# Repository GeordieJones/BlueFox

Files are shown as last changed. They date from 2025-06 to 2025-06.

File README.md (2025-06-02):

# BlueFox

blueFoxLogo_1

**DISCRIPTION:** BlueFox is a modular mesh network system that uses ESP-32 CAM's that take images of a location every 30 minutes then transmit them back to my home computer via LoRa protocol. The network comprises of end nodes (the ESP CAMs); relay nodes (the LoRa-32 cases outside of my house); and the central node (the LoRa-32 at my house). Due to the limited bandwidth of LoRa and the relitave size of the images I decided to change the image to FRAMESIZE_QQVGA in order to make the data needing to be sent to be smaller the code can send larger images it just takes a longer time due to the greater number of packets needing to be sent. Even with the smaller images LoRa cannot send the image with one radio.transmit() so I created hex packets with a header for identification, ending for termination, and checksums to insure all data was received correctly. With this each relay node will collect all the packets for the last one and then move it forward untill it reaches the end. One at the central node it will hex dump all of the data removing headers, endings, and checksums to be copied in to a python script that will remake the image from the hex. Each node is held in a 3D printed PETG case which is weatherproof and has a 5 dBi antenna for increased range.

**Process:** orgininaly the plan was to have the CAM unit be connected to a STM32 microboard which then connected to a LoRa-32 for sending. However this was scrapped due to the large size and wiring which could become seperated in extreme enough weather conditions. It was then decided to use the ESP-32's onboard WiFi chip which allows one board to be the host for another. This choice proved to be optimal due to the lack of physical constraints and WiFi's high bandwidth which allowed for a smaller case with better resistance to disturbances to the case.  

**STM + CAM + LoRa idea:**



**Just CAM + LoRa idea:**



**Testing:** in order to make sure the boxes could hold up to the weather and not short circut in extreme weather conditions I created test boxes. These boxes held a voltage stepper, which was only used becasue it was a small, expendible,and had a LED which could be used to determine if the board survived and could still function. The box also contained a small bit of tissue to indicate whether or not water got into the box or not. I created two boxes PLA (the control group named reaper) and PETG (higher streght material named terminator). These boxes where then ratchet strapped to stands and left outside for a week. The weather during this week included 3 thunderstorms, a flood watch, and two 85 degree sunney days giving the boxes a good test set. Additionaly the boxes where put in a sauna for 30 minutes at 170 degrees.








**RESULTS:** after the week was done the boxes where removed and opened to test the hardware. The tissue was damp on the PLA box and had a few drop marks on the PETG box. Both boxes voltage steppers LED's worked indicating the boxes did there intended job. In the sauna the PLA box did not melt but became extremely soft to the point where you could push a hole in it with almost no effort while the PETG box held firm as expected due to it's higher melting point.

**FINAL MAKE:** with the test complete and the code working I created the final designs to hold the boards, batteries, antennas, and camera. The range of each mesh is around 0.6 miles in a suburban highley wooded area but is dramatically increased if the the senders hight is increased.

Screenshot 2025-05-31 at 7 55 28 PM



**EXTRA NOTES:** When printing with the screws I highly recommend giving youself tolerances as it is very easy to make a screw too big for the hole, I usually use a .2 - .3 mm offset. Additionally, when programming the LoRa it is very important to make sure you are using the Library that matches the chip on your board originaly when I was trying to use the LoRa.h library I was missing packets and getting false data I had to change to the LoRaWan_APP.h library to get my messages to work coherently.

**MATERIALS USED:**  

 **- ESP32-CAM Ai Thinker Model** – [link](https://www.amazon.com/ESP32-CAM-MB-Aideepen-ESP32-CAM-Bluetooth-Arduino/dp/B0948ZFTQZ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)  
 **- Heltec LoRa V3 WiFi** – [link](https://www.amazon.com/dp/B076MSLFC9?ref=ppx_yo2ov_dt_b_fed_asin_title&th=1)  
 **- LiPo Battery** – [link](https://example.com/link-to-cam)  
 **- Antenna** – [link](https://www.amazon.com/dp/B0DLK6BG3L?ref=ppx_yo2ov_dt_b_fed_asin_title)  
 **- PLA Basic** – [link](https://us.store.bambulab.com/products/pla-basic-filament)  
 **- PETG HF** – [link](https://us.store.bambulab.com/products/petg-hf)  

**INSPIRATION:** the cases are each named after a top gun character as maverick is the main character it is the CAM, goose is the wing man and relaying the data, and iceman is the commander and most reliable.
The name blueFox comes from a cold war project that built covert long range image and data transmittion. Hense why this project is named blueFox because it's intention is to be a covert camera sytem that can send images over long ranges.

ChatGPT_Image_Jun_1_2025_at_01_08_06_PM

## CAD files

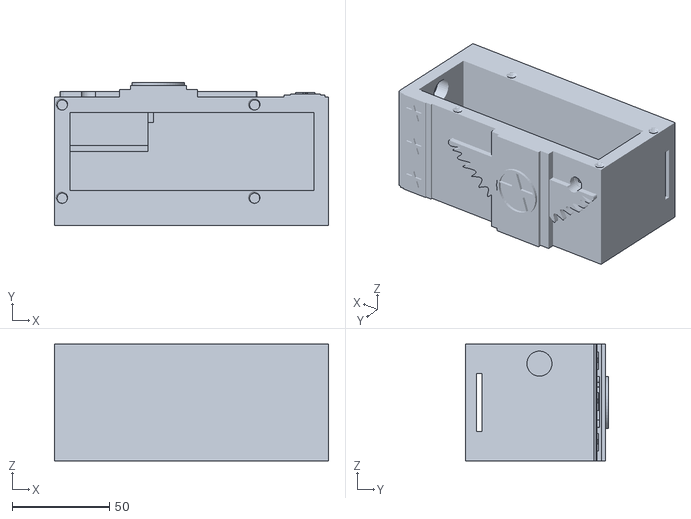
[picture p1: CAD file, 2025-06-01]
STL_files/MAVERICK case.stl
141.0 x 73.5 x 60.0

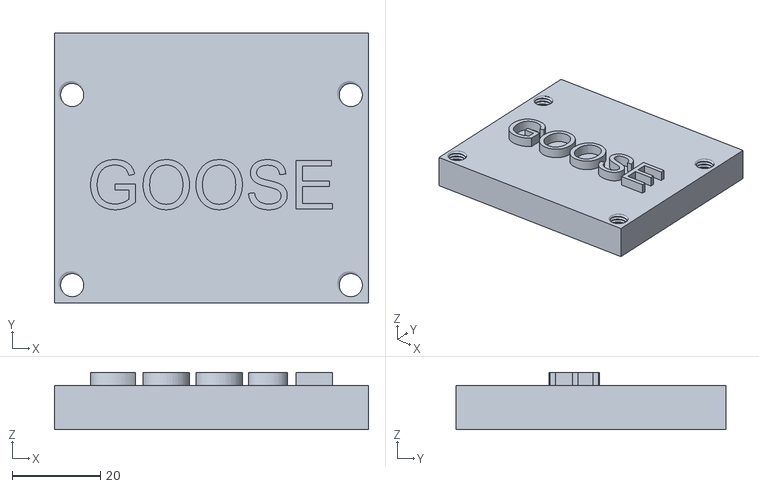
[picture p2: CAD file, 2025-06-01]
STL_files/Goose Top.stl
71.0 x 61.0 x 13.0

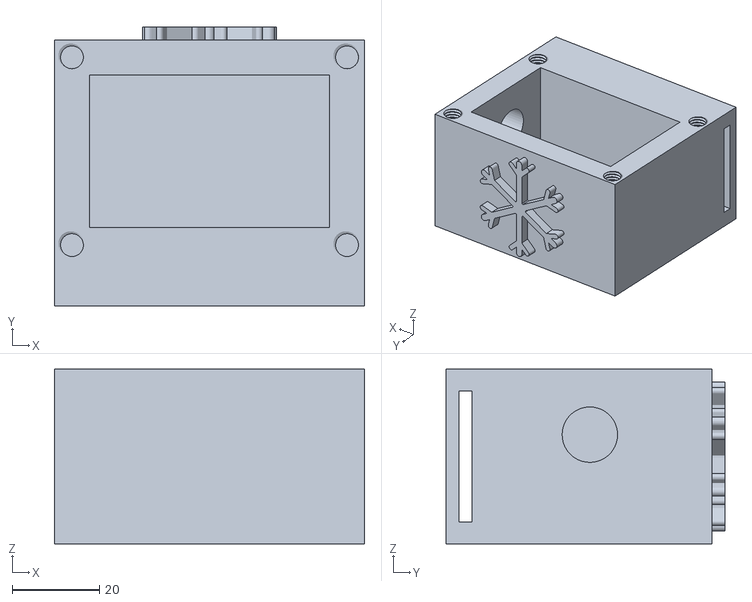
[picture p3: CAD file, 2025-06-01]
STL_files/ICEMAN CASE.stl
71.0 x 64.0 x 40.0

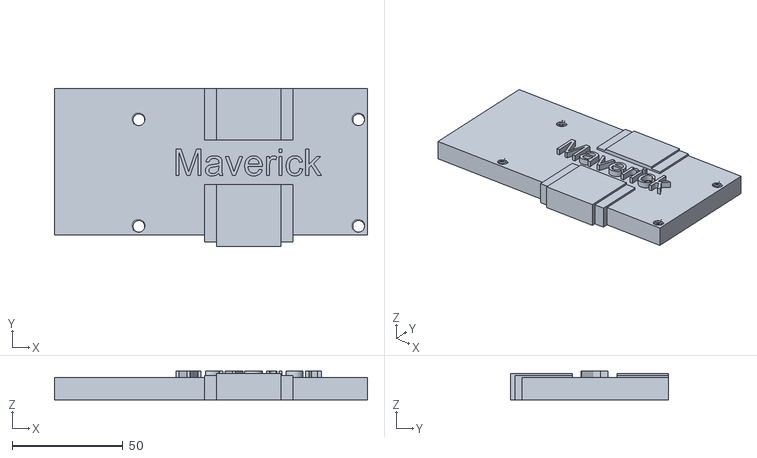
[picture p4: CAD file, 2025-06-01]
STL_files/Maverick top extended.stl
141.0 x 71.0 x 13.0

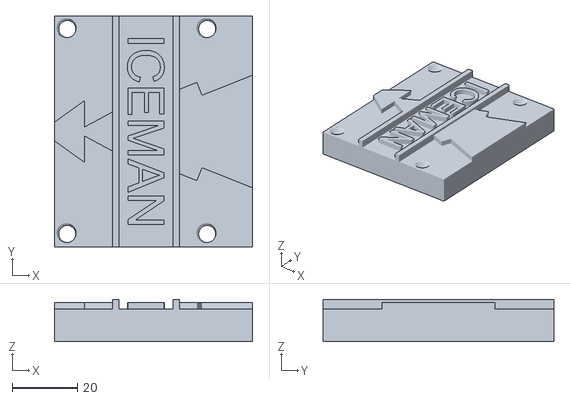
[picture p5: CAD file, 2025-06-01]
STL_files/ICEMAN TOP #1.stl
61.0 x 71.0 x 13.0

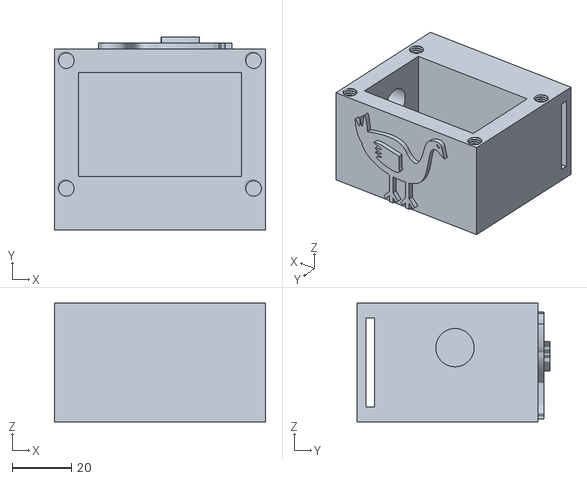
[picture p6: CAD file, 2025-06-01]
STL_files/Goose CASE.stl
71.0 x 65.0 x 40.0

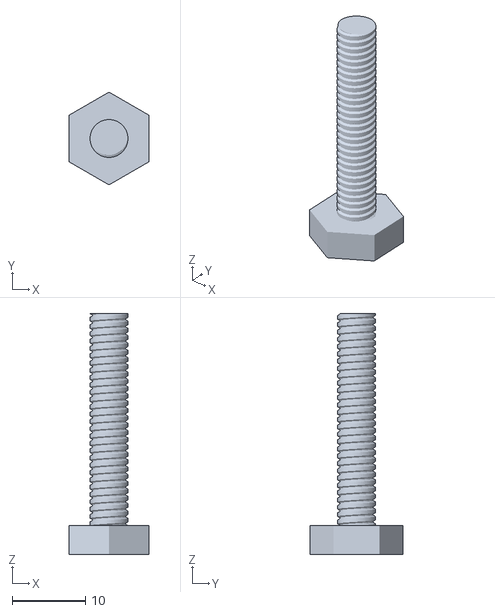
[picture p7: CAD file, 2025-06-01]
STL_files/Screw.stl
11.0 x 12.7 x 33.0

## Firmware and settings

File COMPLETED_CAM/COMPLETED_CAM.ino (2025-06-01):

//ESP CAM code 

#include <WiFi.h>
#include "esp_camera.h"
#include <vector>

// pin defs
#define PWDN_GPIO_NUM    32
#define RESET_GPIO_NUM   -1
#define XCLK_GPIO_NUM     0
#define SIOD_GPIO_NUM    26
#define SIOC_GPIO_NUM    27

#define Y9_GPIO_NUM      35
#define Y8_GPIO_NUM      34
#define Y7_GPIO_NUM      39
#define Y6_GPIO_NUM      36
#define Y5_GPIO_NUM      21
#define Y4_GPIO_NUM      19
#define Y3_GPIO_NUM      18
#define Y2_GPIO_NUM       5
#define VSYNC_GPIO_NUM   25
#define HREF_GPIO_NUM    23
#define PCLK_GPIO_NUM    22

#define LORA_MAX_PACKET 240
#define PACKET_SIZE     230
#define MAX_RETRIES     3
#define ACK_TIMEOUT     2000

const char* ssid = "LoRa_AP";       // AP SSID
const char* host = "192.168.4.1";   // IP of AP (LoRa board)
const int port = 1234;

//packets that image will be broken into
std::vector<std::vector<uint8_t>> allPackets;

void createPacketsDirect(camera_fb_t *fb){
  //removes anything in the array
  allPackets.clear();
  size_t totalBytes = fb->len;
  size_t count = 0;
  uint8_t startSignature[] = {0xAA, 0xBB, 0xCC, 0xDD};
  uint8_t endSignature[]   = {0xEE, 0xFF, 0xAB, 0xCD};

  while(count<totalBytes){
    size_t chunkSize = std::min((size_t)PACKET_SIZE, totalBytes - count);
    std::vector<uint8_t> packet;
    //adding start sig then the data then end sig 
    packet.insert(packet.end(), std::begin(startSignature), std::end(startSignature));
    packet.insert(packet.end(), fb->buf + count, fb->buf + count + chunkSize);
    packet.insert(packet.end(), std::begin(endSignature), std::end(endSignature));
    //packet.push_back((uint8_t)chunkSize));
    uint8_t checksum = 0;
    for (auto b : packet) checksum ^= b;
    packet.push_back(checksum);
    //add to the vector
    allPackets.push_back(packet);
    count += chunkSize;
  }
  //for debugging
  Serial.printf("created %d packets, and the size is %d", allPackets.size(), totalBytes);
}

void sendPacket(WiFiClient &client, int packetIndex){
  //check the index is correct
  if (packetIndex >= allPackets.size()) return;
  //send over the packet
  client.write(allPackets[packetIndex].data(), allPackets[packetIndex].size());
  //send the expected length for debugging
  Serial.printf("sent packet %d\n", packetIndex);
  //need to add in the loop calling the function an ack ping


}

#define uS_TO_S_FACTOR 1000000ULL  // Conversion factor for microseconds to seconds
#define TIME_TO_SLEEP  1800        // Sleep time in seconds (30 minutes)

void setup(){
  Serial.begin(115200);
  delay(1000);

  WiFi.begin(ssid);  // No password
  Serial.print("Connecting to WiFi");
  while (WiFi.status() != WL_CONNECTED) {
    delay(500);
    Serial.print(".");
  }
  Serial.println("\nConnected to WiFi!");
  // Camera init
  camera_config_t config;
  config.ledc_channel = LEDC_CHANNEL_0;
  config.ledc_timer   = LEDC_TIMER_0;
  config.pin_d0       = Y2_GPIO_NUM;
  config.pin_d1       = Y3_GPIO_NUM;
  config.pin_d2       = Y4_GPIO_NUM;
  config.pin_d3       = Y5_GPIO_NUM;
  config.pin_d4       = Y6_GPIO_NUM;
  config.pin_d5       = Y7_GPIO_NUM;
  config.pin_d6       = Y8_GPIO_NUM;
  config.pin_d7       = Y9_GPIO_NUM;
  config.pin_xclk     = XCLK_GPIO_NUM;
  config.pin_pclk     = PCLK_GPIO_NUM;
  config.pin_vsync    = VSYNC_GPIO_NUM;
  config.pin_href     = HREF_GPIO_NUM;
  config.pin_sccb_sda = SIOD_GPIO_NUM;
  config.pin_sccb_scl = SIOC_GPIO_NUM;
  config.pin_pwdn     = PWDN_GPIO_NUM;
  config.pin_reset    = RESET_GPIO_NUM;
  config.xclk_freq_hz = 20000000;
  config.pixel_format = PIXFORMAT_JPEG;
  config.frame_size   = FRAMESIZE_QVGA;
  config.jpeg_quality = 10;
  config.fb_count     = 1;

  esp_err_t err = esp_camera_init(&config);
  if(err != ESP_OK){
    Serial.printf("Camera init failed: 0x%x\n", err);
    while (true);
  }

  camera_fb_t *fb = esp_camera_fb_get();
  if (!fb) {
    Serial.println("Camera capture failed");
    while (true);
  }
  Serial.printf("Captured image: %d bytes\n", fb->len);
  createPacketsDirect(fb);
  Serial.printf("created all packets %d \n",allPackets.size());
  WiFiClient client;
  if (!client.connect(host, port)) {
    Serial.println("Connection to server failed");
    esp_camera_fb_return(fb);
    return;
  }
 
  for(int i = 0; i < allPackets.size(); i++){
    sendPacket(client, i);
    Serial.printf("Packet %d sent, waiting for ACK", i);
    Serial.println();
    unsigned long startTime = millis();
    int maxretiries = 4;
    int retry =0;
    bool ackRecived = false;

    if(retry < maxretiries){
    while (millis() - startTime < 20000){ //20 second watchdog timer
      if(client.available()){
        String response = client.readStringUntil('\n');
        //checks the ACK number so delayed acks dont cause it to fail
        if(response.startsWith("ACK") && response.substring(3).toInt() == i){
          ackRecived = true; 
          Serial.printf("got ACK\n");
          break;
        }else{
          Serial.printf("Unexpected response: %s\n", response.c_str());
          
        }
      }
    }
    // if 20 seconds are up and no response reset
    if(!ackRecived){
      Serial.printf("No Ack Recived for packet %d retrying\n", i);
      i--;
      retry++;
      Serial.printf("Retry %d for packet %d\n", retry, i);
      delay(100);
    }
    }else{
      client.stop();
      esp_camera_fb_return(fb);
      esp_sleep_enable_timer_wakeup(TIME_TO_SLEEP * uS_TO_S_FACTOR);
      esp_deep_sleep_start();
    }

    delay(2000);
  }

  client.stop();
  Serial.printf("All Packets have been sent: %d", allPackets.size());
  Serial.println();
  //serial print the full file to check image on cams end

  for (size_t i = 0; i < allPackets.size(); i++) {
    //Serial.printf("\033[1;33mPacket %03d:\033[0m ", (int)i);
    for (uint8_t b : allPackets[i]) {
      Serial.printf("%02X ", b);
    }
  }
  Serial.println();
  client.stop();
  esp_camera_fb_return(fb);
  Serial.println("Going to sleep now for 30 minutes...");
  esp_sleep_enable_timer_wakeup(TIME_TO_SLEEP * uS_TO_S_FACTOR);
  esp_deep_sleep_start();
}

void loop(){
  //nothing just wait for reset
}

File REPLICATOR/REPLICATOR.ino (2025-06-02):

#include "LoRaWan_APP.h"
#include <vector>

// LoRa Configuration
#define RF_FREQUENCY 915000000
#define TX_OUTPUT_POWER 14
#define LORA_BANDWIDTH 0
#define LORA_SPREADING_FACTOR 7
#define LORA_CODINGRATE 1
#define LORA_PREAMBLE_LENGTH 8
#define LORA_SYMBOL_TIMEOUT 0
#define LORA_FIX_LENGTH_PAYLOAD_ON false
#define LORA_IQ_INVERSION_ON false

// Repeater State
std::vector<uint8_t> receivedImageData;
static RadioEvents_t RadioEvents;
bool lora_idle = true;
bool forwarding = false;
uint8_t txBuffer[250];
unsigned long lastRxTime = 0;
const unsigned long timeout = 3000;

void setup() {
    Serial.begin(115200);
    Mcu.begin(HELTEC_BOARD, SLOW_CLK_TPYE);
    
    // Initialize radio events
    RadioEvents.RxDone = OnRxDone;
    RadioEvents.TxDone = OnTxDone;
    RadioEvents.TxTimeout = OnTxTimeout;
    
    Radio.Init(&RadioEvents);
    Radio.SetChannel(RF_FREQUENCY);
    
    // Configure both RX and TX
    Radio.SetRxConfig(MODEM_LORA, LORA_BANDWIDTH, LORA_SPREADING_FACTOR,
                    LORA_CODINGRATE, 0, LORA_PREAMBLE_LENGTH,
                    LORA_SYMBOL_TIMEOUT, LORA_FIX_LENGTH_PAYLOAD_ON,
                    0, true, 0, 0, LORA_IQ_INVERSION_ON, true);
                    
    Radio.SetTxConfig(MODEM_LORA, TX_OUTPUT_POWER, 0, LORA_BANDWIDTH,
                    LORA_SPREADING_FACTOR, LORA_CODINGRATE,
                    LORA_PREAMBLE_LENGTH, LORA_FIX_LENGTH_PAYLOAD_ON,
                    true, 0, 0, LORA_IQ_INVERSION_ON, 3000);
    
    Serial.println("LoRa Repeater Ready");
    Radio.Rx(0); // Start listening immediately
}

void loop() {
    // Handle timeout for incomplete images
    if(forwarding && millis() - lastRxTime > timeout) {
        Serial.println("Forwarding timeout - sending partial image");
        forwardData();
    }
    
    Radio.IrqProcess();
}

void OnRxDone(uint8_t *payload, uint16_t size, int16_t rssi, int8_t snr) {
    lastRxTime = millis();
    
    // Minimum viable packet size (2B header + 4B footer + 1B checksum)
    if(size < 7) {
        Serial.println("Packet too small, ignoring");
        Radio.Rx(0);
        return;
    }

    // Strip header bytes (CC DD)
    uint8_t* packetData = payload + 2;
    uint16_t dataSize = size - 2;

    // Search for JPEG end marker (FF D9)
    uint16_t jpegEnd = 0;
    bool foundJpegEnd = false;
    for(uint16_t i = 0; i < dataSize - 1; i++) {
        if(packetData[i] == 0xFF && packetData[i+1] == 0xD9) {
            jpegEnd = i + 2;
            foundJpegEnd = true;
            break;
        }
    }

    // Search for footer pattern (EE FF AB CD)
    uint16_t footerPos = 0;
    bool foundFooter = false;
    for(uint16_t i = 0; i < dataSize - 3; i++) {
        if(packetData[i] == 0xEE && 
           packetData[i+1] == 0xFF && 
           packetData[i+2] == 0xAB && 
           packetData[i+3] == 0xCD) {
            footerPos = i;
            foundFooter = true;
            break;
        }
    }

    // Determine what to store
    uint16_t bytesToStore = foundJpegEnd ? jpegEnd : (foundFooter ? footerPos : dataSize);
    
    // Store the image data
    for(uint16_t i = 0; i < bytesToStore; i++) {
        receivedImageData.push_back(packetData[i]);
    }

    // Immediately forward the packet
    if(bytesToStore > 0) {
        memcpy(txBuffer, payload, size); // Forward the original packet
        forwarding = true;
        Radio.Send(txBuffer, size);
    } else {
        Radio.Rx(0);
    }

    Serial.printf("Received %d bytes | Forwarding %d bytes [RSSI: %d, SNR: %d]%s%s\n",
                 bytesToStore, size, rssi, snr,
                 foundFooter ? " [Footer]" : "",
                 foundJpegEnd ? " [JPEG End]" : "");
}

void forwardData() {
    if(receivedImageData.empty()) {
        Serial.println("No data to forward");
        forwarding = false;
        Radio.Rx(0);
        return;
    }

    // Add your forwarding logic here if you want to process the complete image
    // Otherwise it's already forwarding packets immediately in OnRxDone
    
    receivedImageData.clear();
    forwarding = false;
    Radio.Rx(0);
}

void OnTxDone(void) {
    Serial.println("Forwarding complete");
    lora_idle = true;
    forwarding = false;
    Radio.Rx(0); // Go back to receive mode
}

void OnTxTimeout(void) {
    Serial.println("Forwarding timeout");
    lora_idle = true;
    forwarding = false;
    Radio.Rx(0);
}

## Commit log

2025-06-01 Add all STL files in STL_files folder
    [Goose CASE.stl, Goose Top.stl, ICEMAN CASE.stl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]
2025-06-01 Save current changes before pull
2025-06-01 Replace MAVERICK case extended.stl with MAVERICK case.stl
    [MAVERICK case extended.stl, MAVERICK case.stl]
